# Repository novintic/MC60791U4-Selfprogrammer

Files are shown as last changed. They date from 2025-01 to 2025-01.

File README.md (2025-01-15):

This is a take at the MC68701/U4 self- programmer board published in application note AN906A/D by Motorola in 1987.

It allows the 'self-programming' of the MC68701(U4) microcontroller (basically an 6801 with built in Eprom).

Probably the only conceivable use for this thing nowadays is to program a 68701U4 to be used as a replacement for the custom 'PS4' chip on a Bubble Bobble arcade PCB. But if you read this you'll most likely already know that.

MC68701U4s are still more or less readily available on Ebay (either NOS or used).

Some additions and modifications to the original design have been made:
 - redesigned the power supply for the +21V programming voltage using an MC34063 based boost converter circuit
 - uses 27C512 ROMS as these are easily available and dirt cheap
 - Added a Vpp- Voltage LED: will light dim when 5V present and bright wenn 21V Vpp is switched on.

Usage: 
 - Eprom U3 must be programmed with the minprgu4.bin which contains the selfprogramming- code
 - Eprom U4 contains the image to be programmed to the MCU's Eprom (most likely 'a78-01.17' found in the 'bin'- folder).
 - Turn off Power (SW1), put SW2 in 'RESET' position
 - Insert the MC68701U4
 - Switch power on.'PWR' LED should light. 'Vpp' LED will be off (indicating /RST is low)
 - Switch SW2 to 'PRGRM'. 'Vpp' will light dim indicating 5V present at /RST which will take the MCU out of reset and rum minprgu4. At the same time LED 'BLANK' should light indicating blank check. If this check fails, both 'BLANK' and 'FAIL' LEDs will light.
 - If blank- check passes, minprgu4 will switch on Vpp. 'Vpp'- LED will light brightly. Programming of the MCU starts and will take approximately 4 minutes.
 - If programming was successful - which means that the data has been verified correctly - LED 'PASS' will light. If not, LED 'FAIL' will light.

-----------------------------------------------------------------------------------------------
IMPORTANT!

MINPRGU4 must be located from $1850-$1FFF on EPROM U3 (NOT starting from $1800 as the instructions in 'Self-Programming the MC68701/U4 document could be understood).

The Program on U4 must be at $1000-$1FFF on the EPROM U4 for MC68701U4 (for MC68701: $1800-$1FFF)

-----------------------------------------------------------------------------------------------

You can find more info here (also, most of the above changes are based on suggestions from this thread):
https://www.eevblog.com/forum/microcontrollers/self-programming-the-mc68701-and-the-mc68701u4-(motorola)/

This is another quick/messy release. the files have not really been cleaned up. You should be able to upload 'gerber.zip' to your favorite PCB manufacturer.

The board has been tested and works well for us, however, we'll not be able to offer any kind of support.  Please use at your own risk, thank you.

mirko(NOVINTIC) 01/2025

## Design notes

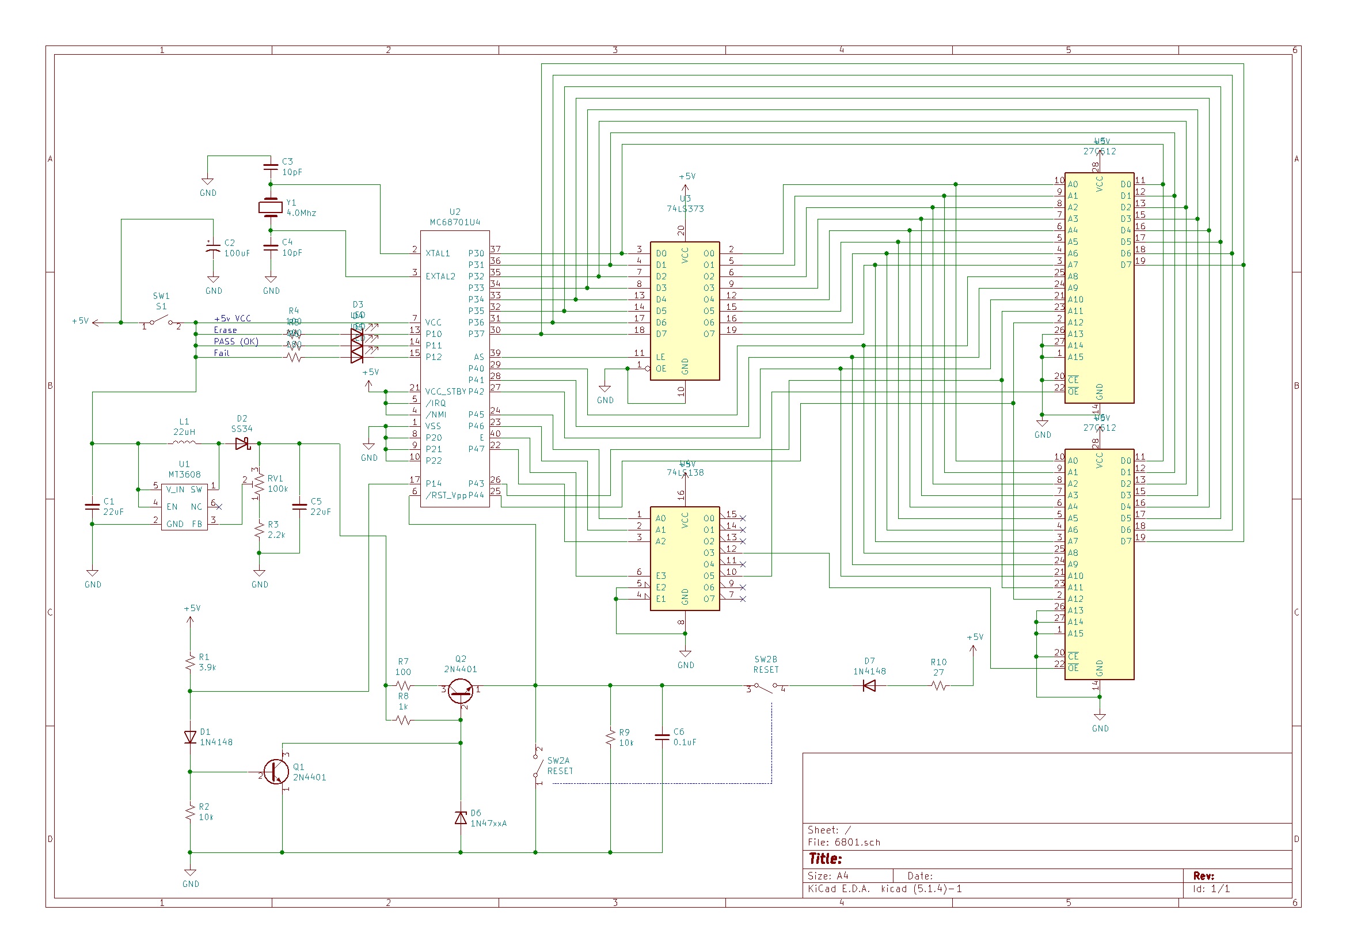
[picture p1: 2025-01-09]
Doc/68701u4.jpg

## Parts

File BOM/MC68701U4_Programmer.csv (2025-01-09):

Reference | Value | Footprint | Qty
C1 | 470uF(?) | Capacitor_THT:CP_Radial_D5.0mm_P2.50mm | 1
C2 | 1123pF | Capacitor_THT:C_Disc_D3.0mm_W2.0mm_P2.50mm | 1
C3 | 63uF | Capacitor_THT:CP_Radial_D5.0mm_P2.50mm | 1
C4,C5 | 10pF | Capacitor_THT:C_Disc_D3.0mm_W2.0mm_P2.50mm | 2
C6 | 100uF | Capacitor_THT:CP_Radial_D5.0mm_P2.50mm | 1
C7 | .1uF | Capacitor_THT:C_Disc_D3.0mm_W2.0mm_P2.50mm | 1
D1 | 1N5818/5819/5820 | Diode_THT:D_DO-34_SOD68_P7.62mm_Horizontal | 1
D2 | PWR | LED_THT:LED_D5.0mm_Clear | 1
D3 | Erase | LED_THT:LED_D5.0mm | 1
D4 | Pass (OK) | LED_THT:LED_D5.0mm | 1
D5 | Fail | LED_THT:LED_D5.0mm | 1
D6,D8 | D_Small | Diode_THT:D_DO-34_SOD68_P7.62mm_Horizontal | 2
D7 | 1N4748/1N5251 | Diode_THT:D_DO-34_SOD68_P7.62mm_Horizontal | 1
D9 | Vpp | LED_THT:LED_D5.0mm | 1
J1 | +5Vin | TerminalBlock:TerminalBlock_bornier-2_P5.08mm | 1
L1 | 88uH | footprints:IND_FIT68-1 | 1
Q1,Q2 | BC547 | Package_TO_SOT_THT:TO-92_HandSolder | 2
R1 | 1K | Resistor_THT:R_Axial_DIN0207_L6.3mm_D2.5mm_P10.16mm_Horizontal | 1
R2 | 20K | Resistor_THT:R_Axial_DIN0207_L6.3mm_D2.5mm_P10.16mm_Horizontal | 1
R3 | 0.23R | Resistor_THT:R_Axial_DIN0207_L6.3mm_D2.5mm_P10.16mm_Horizontal | 1
R4 | 180R | Resistor_THT:R_Axial_DIN0207_L6.3mm_D2.5mm_P10.16mm_Horizontal | 1
R5,R6,R7,R8 | 470R | Resistor_THT:R_Axial_DIN0207_L6.3mm_D2.5mm_P10.16mm_Horizontal | 4
R9 | 3.9K | Resistor_THT:R_Axial_DIN0207_L6.3mm_D2.5mm_P10.16mm_Horizontal | 1
R10,R12,R13 | 10K | Resistor_THT:R_Axial_DIN0207_L6.3mm_D2.5mm_P10.16mm_Horizontal | 3
R11 | 100R | Resistor_THT:R_Axial_DIN0207_L6.3mm_D2.5mm_P10.16mm_Horizontal | 1
R14 | 27R | Resistor_THT:R_Axial_DIN0207_L6.3mm_D2.5mm_P10.16mm_Horizontal | 1
R15 | 2K | Resistor_THT:R_Axial_DIN0207_L6.3mm_D2.5mm_P10.16mm_Horizontal | 1
SW1 | SW_DPDT_x2 | footprints:SW_GF-126-0159 | 1
SW2 | RST/PRG | footprints:SW_GF-126-0159 | 1
U1 | 74LS138 | Package_DIP:DIP-16_W7.62mm_Socket_LongPads | 1
U2 | 74LS373 | Package_DIP:DIP-20_W7.62mm_Socket_LongPads | 1
U3,U4 | 27C512 | Package_DIP:DIP-28_W15.24mm | 2
U5 | ~ | Package_DIP:DIP-40_W15.24mm_Socket_LongPads | 1
U6 | MC34063AD | Package_SO:SOIC-8_3.9x4.9mm_P1.27mm | 1
Y1 | 4Mhz | Crystal:Crystal_HC50_Vertical | 1

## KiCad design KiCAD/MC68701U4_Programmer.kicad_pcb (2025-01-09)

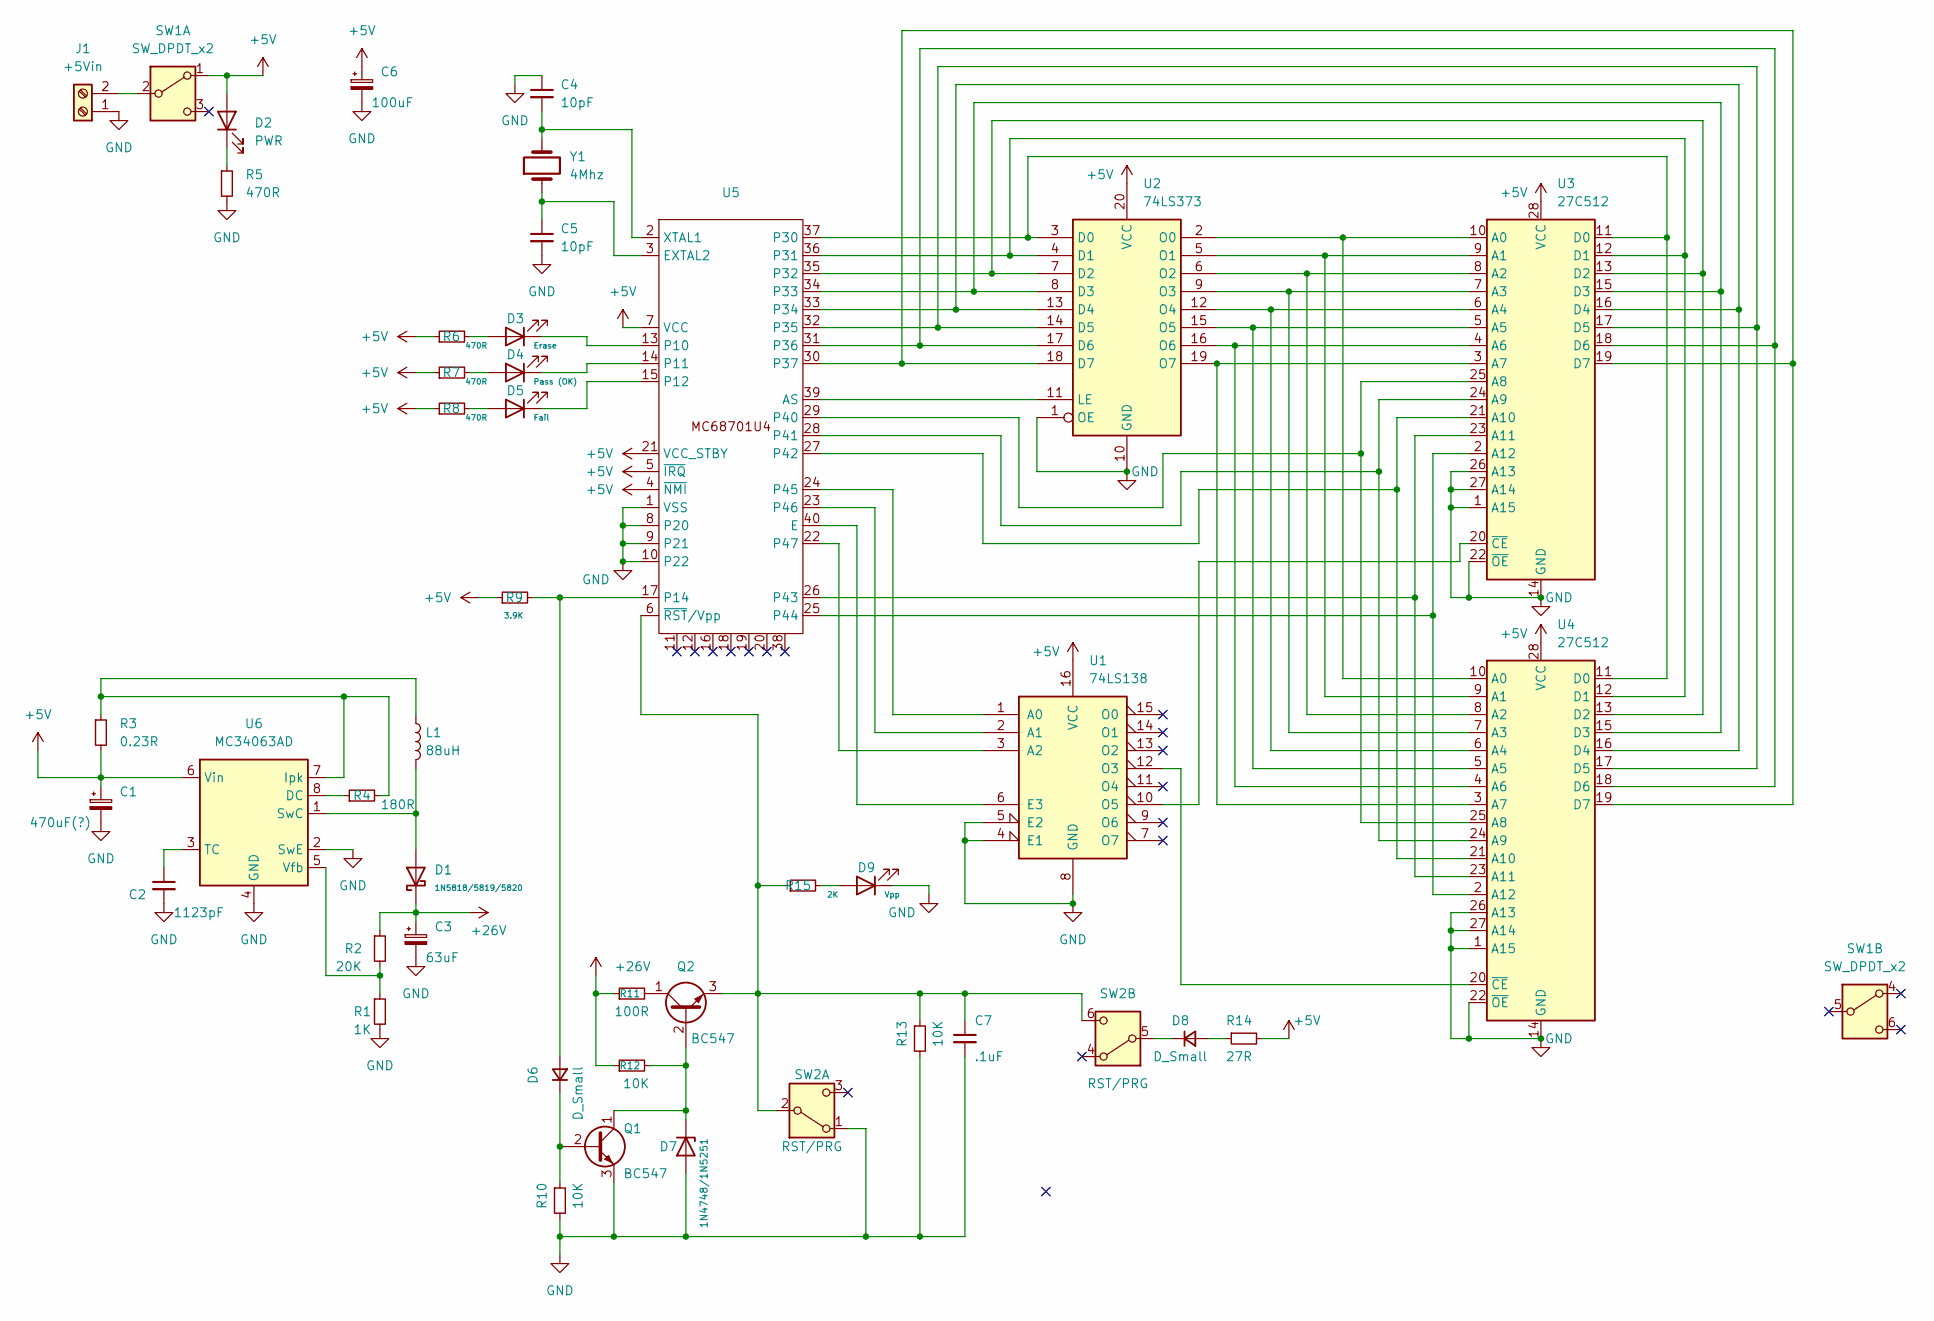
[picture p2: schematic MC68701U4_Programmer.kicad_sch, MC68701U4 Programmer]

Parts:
C1: 470uF(?); CP_Radial_D5.0mm_P2.50mm
C2: 1123pF; C_Disc_D3.0mm_W2.0mm_P2.50mm
C3: 63uF; CP_Radial_D5.0mm_P2.50mm
C4, C5: 10pF; C_Disc_D3.0mm_W2.0mm_P2.50mm
C6: 100uF; CP_Radial_D5.0mm_P2.50mm
C7: .1uF; C_Disc_D3.0mm_W2.0mm_P2.50mm
D1: 1N5818/5819/5820; D_DO-34_SOD68_P7.62mm_Horizontal
D2: PWR; LED_D5.0mm_Clear
D3: Erase; LED_D5.0mm
D4: Pass (OK); LED_D5.0mm
D5: Fail; LED_D5.0mm
D6, D8: D_Small; D_DO-34_SOD68_P7.62mm_Horizontal
D7: 1N4748/1N5251; D_DO-34_SOD68_P7.62mm_Horizontal
D9: Vpp; LED_D5.0mm
J1: +5Vin; TerminalBlock_bornier-2_P5.08mm
L1: 88uH; IND_FIT68-1
Q1, Q2: BC547; TO-92_HandSolder
R1: 1K; R_Axial_DIN0207_L6.3mm_D2.5mm_P10.16mm_Horizontal
R2: 20K; R_Axial_DIN0207_L6.3mm_D2.5mm_P10.16mm_Horizontal
R3: 0.23R; R_Axial_DIN0207_L6.3mm_D2.5mm_P10.16mm_Horizontal
R4: 180R; R_Axial_DIN0207_L6.3mm_D2.5mm_P10.16mm_Horizontal
R5, R6, R7, R8: 470R; R_Axial_DIN0207_L6.3mm_D2.5mm_P10.16mm_Horizontal
R9: 3.9K; R_Axial_DIN0207_L6.3mm_D2.5mm_P10.16mm_Horizontal
R10, R12, R13: 10K; R_Axial_DIN0207_L6.3mm_D2.5mm_P10.16mm_Horizontal
R11: 100R; R_Axial_DIN0207_L6.3mm_D2.5mm_P10.16mm_Horizontal
R14: 27R; R_Axial_DIN0207_L6.3mm_D2.5mm_P10.16mm_Horizontal
R15: 2K; R_Axial_DIN0207_L6.3mm_D2.5mm_P10.16mm_Horizontal
SW1: SW_DPDT_x2; SW_GF-126-0159
SW2: RST/PRG; SW_GF-126-0159
U1: 74LS138; DIP-16_W7.62mm_Socket_LongPads
U2: 74LS373; DIP-20_W7.62mm_Socket_LongPads
U3, U4: 27C512; DIP-28_W15.24mm
U5: DIP-40_W15.24mm_Socket_LongPads
U6: MC34063AD; SOIC-8_3.9x4.9mm_P1.27mm
Y1: 4Mhz; Crystal_HC50_Vertical

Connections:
+5V: C1.1, C6.1, D2.2 (A), R3.2, R6.1, R7.1, R8.1, R9.1, R14.2, SW1.1 (A), U1.16 (VCC), U2.20 (VCC), U3.28 (VCC), U4.28 (VCC), U5.4 (~NMI), U5.5 (~IRQ), U5.7 (VCC), U5.21 (VCC_STBY), U6.6 (Vin)
+26V: C3.1, D1.1 (K), R2.1, R11.1, R12.1
GND: C1.2, C2.2, C3.2, C4.1, C5.2, C6.2, C7.2, D7.2 (A), D9.1 (K), J1.1, Q1.3 (E), R1.2, R5.2, R10.2, R13.2, SW2.1 (A), U1.4 (E1), U1.5 (E2), U1.8 (GND), U2.1 (OE), U2.10 (GND), U3.1 (A15), U3.14 (GND), U3.22 (~OE), U3.26 (A13), U3.27 (A14), U4.1 (A15), U4.14 (GND), U4.22 (~OE), U4.26 (A13), U4.27 (A14), U5.1 (VSS), U5.8 (P20), U5.9 (P21), U5.10 (P22), U6.2 (SwE), U6.4 (GND)
unnamed: D1.2 (A), L1.2, U6.1 (SwC)
unnamed: D2.1 (K), R5.1
unnamed: D3.2 (A), R6.2
unnamed: D3.1 (K), U5.13 (P10)
unnamed: D4.2 (A), R7.2
unnamed: D4.1 (K), U5.14 (P11)
unnamed: D5.2 (A), R8.2
unnamed: D5.1 (K), U5.15 (P12)
unnamed: D6.2 (A), R9.2, U5.17 (P14)
unnamed: D6.1 (K), Q1.2 (B), R10.1
unnamed: D7.1 (K), Q1.1 (C), Q2.2 (B), R12.2
unnamed: D8.2 (A), R14.1
unnamed: D8.1 (K), SW2.5 (B)
unnamed: D9.2 (A), R15.2
unnamed: J1.2, SW1.2 (B)
unnamed: Q2.1 (C), R11.2
unnamed: C7.1, Q2.3 (E), R13.1, R15.1, SW2.2 (B), SW2.6 (C), U5.6 (~RST/Vpp)
unnamed: U1.1 (A0), U5.24 (P45)
unnamed: U1.2 (A1), U5.23 (P46)
unnamed: U1.3 (A2), U5.22 (P47)
unnamed: U1.6 (E3), U5.40 (E)
unnamed: U1.12 (O3), U4.20 (~CE)
unnamed: U1.10 (O5), U3.20 (~CE)
unnamed: U2.3 (D0), U3.11 (D0), U4.11 (D0), U5.37 (P30)
unnamed: U2.4 (D1), U3.12 (D1), U4.12 (D1), U5.36 (P31)
unnamed: U2.7 (D2), U3.13 (D2), U4.13 (D2), U5.35 (P32)
unnamed: U2.8 (D3), U3.15 (D3), U4.15 (D3), U5.34 (P33)
unnamed: U2.13 (D4), U3.16 (D4), U4.16 (D4), U5.33 (P34)
unnamed: U2.14 (D5), U3.17 (D5), U4.17 (D5), U5.32 (P35)
unnamed: U2.17 (D6), U3.18 (D6), U4.18 (D6), U5.31 (P36)
unnamed: U2.18 (D7), U3.19 (D7), U4.19 (D7), U5.30 (P37)
unnamed: U2.11 (LE), U5.39 (AS)
unnamed: U2.2 (O0), U3.10 (A0), U4.10 (A0)
unnamed: U2.5 (O1), U3.9 (A1), U4.9 (A1)
unnamed: U2.6 (O2), U3.8 (A2), U4.8 (A2)
unnamed: U2.9 (O3), U3.7 (A3), U4.7 (A3)
unnamed: U2.12 (O4), U3.6 (A4), U4.6 (A4)
unnamed: U2.15 (O5), U3.5 (A5), U4.5 (A5)
unnamed: U2.16 (O6), U3.4 (A6), U4.4 (A6)
unnamed: U2.19 (O7), U3.3 (A7), U4.3 (A7)
unnamed: U3.25 (A8), U4.25 (A8), U5.29 (P40)
unnamed: U3.24 (A9), U4.24 (A9), U5.28 (P41)
unnamed: U3.21 (A10), U4.21 (A10), U5.27 (P42)
unnamed: U3.23 (A11), U4.23 (A11), U5.26 (P43)
unnamed: U3.2 (A12), U4.2 (A12), U5.25 (P44)
unnamed: C5.1, U5.3 (EXTAL2), Y1.1
unnamed: C4.2, U5.2 (XTAL1), Y1.2
unnamed: R4.1, U6.8 (DC)
unnamed: L1.1, R3.1, R4.2, U6.7 (Ipk)
unnamed: C2.1, U6.3 (TC)
unnamed: R1.1, R2.2, U6.5 (Vfb)

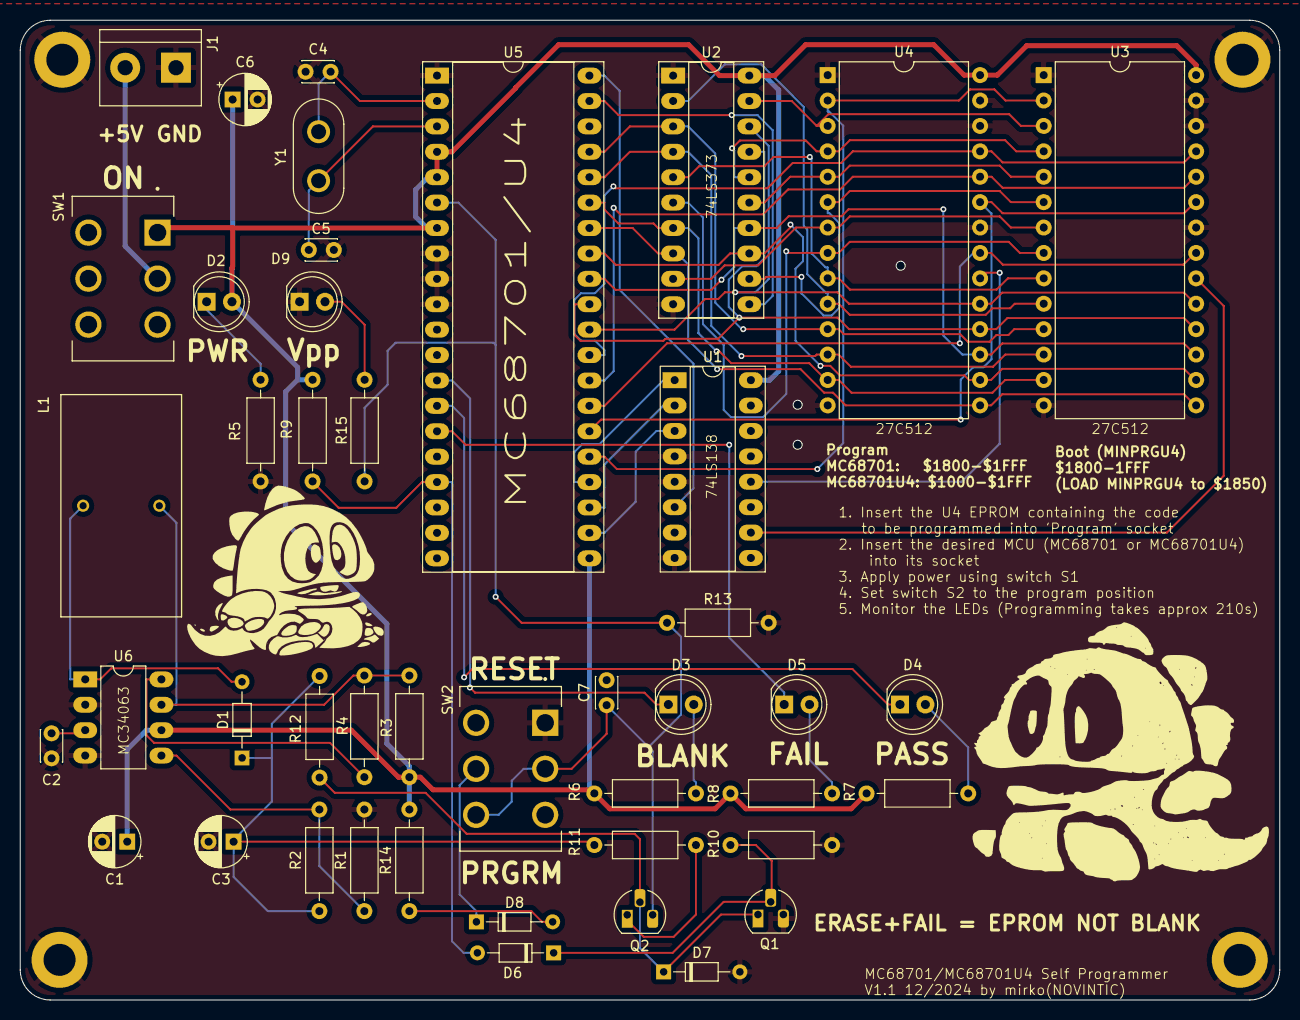
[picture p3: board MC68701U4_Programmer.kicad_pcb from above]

Board: 2 copper layers, 125.9 x 98.0 mm, 44 parts (0 on the bottom side), 54 nets.

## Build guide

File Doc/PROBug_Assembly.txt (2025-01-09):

I corrected the error, rechecked your work and changed the index back.   I reformatted things just so they line up to make it easier to read.    I ran it through if you want to check the listing file below.   I also included the S record.  Do you have a PROM programmer and part to load this code into?   If so, I think it's time to build up the circuit.   If you need help understanding how to build it, let me know.  You could do this on some white board for the small number of parts you want to program. 

S00A000042595445425547E3
S10B0080000000000000000074
S123B8508E00FF860797009702CEF800DF84C600A6001126298CFFFF27030820F3860697A3
S123B87002DF86CE004609CCC350D3097F0008DD0B8640950827FC8C000026EA20068683B5
S123B8909702205DCE7000DF80CE7FFFDF82CEC350DF86DE843CDE803C86FE9714A600DE03
S123B8B084A70008DF8486FC9714DC86D3097F0008DD0B8640950827FC38089C8223D9869E
S123B8D0FF971438DF84CE70003CA600DE84E60011261008DF8438088C800026EC868497F6
S10CB8F00220FE8682970220F872
S113BFF0B8F1B8F1B8F1B8F1B8F1B8F1B8F1B85096
S9030000FC

M6801 Portable Cross Assembler  0.05   MS-DOS/PC-DOS  Page 1
 Sat May 18 20:37:13 2019
Command line:
 C:\6801\PASM01.EXE -dxs -l BYTEBUG.lst BYTEBUG.asm
Options list:
ON  - b - Printing of macro definitions
ON  - c - Printing of macro calls
ON  - d - Placing of symbolic debugging information in COFF  (changed)
OFF - e - Printing of macro expansions
ON  - f - Printing of conditional directives
OFF - g - Printing of generated constants list
OFF - q - Expanding and printing of structured syntax
ON  - s - Printing of symbol table  (changed)
OFF - u - Printing of conditional unassembled source
ON  - x - Printing of cross reference table  (changed)
OFF - m - Suppress printing of error messages
ON  - w - Printing of warning messages
OFF - v - Suppress printing of updated status
OFF - y - Enabling of sgs extensions
ON  - o - Create object code
ON  -   - Formatting of source line listing
Create listing file - l - BYTEBUG.lst
 
Xdefs:
  NONE
 
Xrefs:
  NONE

Input file(s): BYTEBUG.asm (142 lines)
 
Output file: BYTEBUG.o 
Listing file: BYTEBUG.lst

M6801 Portable Cross Assembler  0.05  BYTEBUG.asm  Page 2
 Sat May 18 20:37:13 2019 
Options - MD,MC,NOG,NOU,W,NOMEX,CL,FMT,O
 
LINE   S PC   OPCO OPERANDS S LABEL    MNEMO OPERANDS COMMENT
00001                         *
00002                         *
00003                         * THIS PROGRAM WILL CHECK, PROGRAM AND VERIFY
00004                         * THE MC68701U4 ' S EPROM.
00005                         *
00006                         *
00007                         *         E Q U A T E S
00008  P 0000      0000     A P1DDR    EQU   $00      PORT 1 DATA DIR. REGISTER
00009  P 0000      0002     A P1DR     EQU   $02      PORT 1 DATA REGISTER
00010  P 0000      0008     A TCSR     EQU   $08      TIMER CONTROL/STAT REGISTER
00011  P 0000      0009     A TIMER    EQU   $09      COUNTER REGISTER
00012  P 0000      000b     A OUTCMP   EQU   $0B      OUTPUT COMPARE REGISTER
00013  P 0000      0014     A EPMCNT   EQU   $14      RAM/EROM CONTROL REGISTER
00014                         *
00015                         *         L O C A L       V A R I A B L E S
00016                         *
00017  A 0080                          ORG   $80     
00018  A 0080      02       A IMBEG    RMB   2        START OF MEMORY BLOCK
00019  A 0082      02       A IMEND    RMB   2        LAST BYTE OF MEMORY BLOCK
00020  A 0084      02       A PNTR     RMB   2        FIRST BYTE OF EPROM TO RE PGM'D
00021  A 0086      02       A WAIT     RMB   2        COUNTER VALUE
00022                         *
00023  A b850                          ORG   $B850   
00024  A b850 8e   00ff     A START    LDS   #$FF     INITIALIZE STACK
00025  A b853 86   07       A          LDAA  #$07     INIT. PORT 1
00026  A b855 97   00       A          STAA  P1DDR    DDR
00027  A b857 97   02       A          STAA  P1DR     DATA REGISTER (ALL LED'S OFF)
00028                         **
00029  A b859 ce   f800     A          LDX   #$F800   CHECK IF EPROM ERASED
00030  A b85c df   84       A          STX   PNTR     INIT. PNTR WHILE CONVENIENT
00031  A b85e c6   00       A          LDAB  #$00     GET READY FOR CMPR.
00032  A b860 a6   00       A ERASE    LDAA  0,X      LOAD EPROM CONTENTS
00033  A b862 11                       CBA            COMPARE TO ZERO
00034  A b863 26   29    b88e          BNE   ERROR1   BRANCH IF NOT ZERO
00035  A b865 8c   ffff     A          CPX   #$FFFF   
00036  A b868 27   03    b86d          BEQ   NEXT     IF SO BRANCH
00037  A b86a 08                       INX            GO AGAIN
00038  A b86b 20   f3    b860          BRA   ERASE   
00039                         **
00040  A b86d 86   06       A NEXT     LDAA  #$06     TURN ON ERASED LED
00041  A b86f 97   02       A          STAA  P1DR     
00042                         **
00043                         * WAIT FOR VPP TO REACH 21V (3.5 SEC.)
00044                         *
00045  A b871 df   86       A          STX   WAIT     
00046  A b873 ce   0046     A          LDX   #$0046   
00047  A b876 09              STALL1   DEX           
00048  A b877 cc   c350     A          LDD   #$C350   INIT. 50MS LOOP
00049  A b87a d3   09       A          ADDD  TIMER    BUMP CURRENT VALUE
00050  A b87c 7f   0008     A          CLR   TCSR     CLEAR OCF
00051  A b87f dd   0b       A          STD   OUTCMP   SET OUTPUT COMPARE
00052  A b881 86   40       A          LDAA  #$40     NOW WAIT FOR OFC

M6801 Portable Cross Assembler  0.05  BYTEBUG.asm  Page 3
 Sat May 18 20:37:13 2019 
Options - MD,MC,NOG,NOU,W,NOMEX,CL,FMT,O
 
LINE   S PC   OPCO OPERANDS S LABEL    MNEMO OPERANDS COMMENT
00053  A b883 95   08       A STALL2   BITA  TCSR     
00054  A b885 27   fc    b883          BEQ   STALL2   NOT YET
00055  A b887 8c   0000     A          CPX   #$0000   70 TIMES YET?
00056  A b88a 26   ea    b876          BNE   STALL1   NOPE
00057  A b88c 20   06    b894          BRA   PGINT   
00058                         **
00059  A b88e 86   83       A ERROR1   LDAA  #$83     LIGHT ERROR LED ONLY
00060  A b890 97   02       A          STAA  P1DR     
00061  A b892 20   5d    b8f1          BRA   SELF     
00062                         **
00063  A b894 ce   7000     A PGINT    LDX   #$7000   INIT. IMBEG
00064  A b897 df   80       A          STX   IMBEG   
00065  A b899 ce   7fff     A          LDX   #$7FFF   INIT. IMEND
00066  A b89c df   82       A          STX   IMEND   
00067  A b89e ce   c350     A          LDX   #$C350   INIT. WAIT (4.0 MHZ)
00068  A b8a1 df   86       A          STX   WAIT     
00069                         *
00070                         * THIS PART FROM 68701U4 DATA SHEET
00071                         *
00072  A b8a3 de   84       A EPROM    LDX   PNTR     SAVE CALLING ARGUMENT
00073  A b8a5 3c                       PSHX           RESTORE WHEN DONE
00074  A b8a6 de   80       A          LDX   IMBEG    USE STACK
00075                         *
00076  A b8a8 3c              EPRO02   PSHX           SAVE POINTER ON STACK
00077  A b8a9 86   fe       A          LDAA  #$FE     REMOVE VPP, SET LATCH
00078  A b8ab 97   14       A          STAA  EPMCNT   PPC=1,PLC=0
00079  A b8ad a6   00       A          LDAA  0,X      MOVE DATA MEMORY-TO-LATCH
00080  A b8af de   84       A          LDX   PNTR     GET WHERE TO PUT IT
00081  A b8b1 a7   00       A          STAA  0,X      STASH AND LATCH
00082  A b8b3 08                       INX            NEXT ADDR.
00083  A b8b4 df   84       A          STX   PNTR     ALL SET FOR NEXT
00084  A b8b6 86   fc       A          LDAA  #$FC     ENABLE EPROM POWER (VPP)
00085  A b8b8 97   14       A          STAA  EPMCNT   PPC=0,PLC=0
00086                         *
00087                         * NOW WAIT 50 MSEC TIMEOUT USING COMPARE
00088                         *
00089  A b8ba dc   86       A          LDD   WAIT     GET CYCLE COUNTER
00090  A b8bc d3   09       A          ADDD  TIMER    BUMP CURRENT VALUE
00091  A b8be 7f   0008     A          CLR   TCSR     CLEAR OCF
00092  A b8c1 dd   0b       A          STD   OUTCMP   SET OUTPUT COMPARE
00093  A b8c3 86   40       A          LDAA  #$40     NOW WAIT FOR OCF
00094  A b8c5 95   08       A EPRO04   BITA  TCSR     
00095  A b8c7 27   fc    b8c5          BEQ   EPRO04   NOT YET
00096                         *
00097  A b8c9 38                       PULX           SET UP FOR NEXT ONE
00098  A b8ca 08                       INX            NEXT
00099  A b8cb 9c   82       A          CPX   IMEND    MAYBE DONE
00100  A b8cd 23   d9    b8a8          BLS   EPRO02   NOT YET
00101  A b8cf 86   ff       A          LDAA  #$FF     REMOVE VPP, INHIBIT LATCH
00102  A b8d1 97   14       A          STAA  EPMCNT   EPROM CAN NOW RE READ
00103  A b8d3 38                       PULX           RESTORE PNTR
00104  A b8d4 df   84       A          STX   PNTR     

M6801 Portable Cross Assembler  0.05  BYTEBUG.asm  Page 4
 Sat May 18 20:37:13 2019 
Options - MD,MC,NOG,NOU,W,NOMEX,CL,FMT,O
 
LINE   S PC   OPCO OPERANDS S LABEL    MNEMO OPERANDS COMMENT
00105                         * *
00106                         * START NEW CODE
00107                         *
00108  A b8d6 ce   7000     A          LDX   #$7000   SET UP POINTER
00109  A b8d9 3c              VERF2    PSHX           SAVE POINTER ON STACK
00110  A b8da a6   00       A          LDAA  0,X      GET DESIRED DATA
00111  A b8dc de   84       A          LDX   PNTR     GET EPROM ADDR.
00112  A b8de e6   00       A          LDAB  0,X      GET DATA TO BE CHECKED
00113  A b8e0 11                       CBA            CHECK IF SAME
00114  A b8e1 26   10    b8f3          BNE   ERROR2   BRANCH IF ERROR(LIGHT LED)
00115  A b8e3 08                       INX            NEXT ADDR
00116  A b8e4 df   84       A          STX   PNTR     ALL SET FOR NEXT
00117  A b8e6 38                       PULX           SETUP FOR NEXT ONE
00118  A b8e7 08                       INX            NEXT
00119  A b8e8 8c   8000     A          CPX   #$8000   MAYBE DONE
00120  A b8eb 26   ec    b8d9          BNE   VERF2    NOT YET
00121                         **
00122  A b8ed 86   84       A          LDAA  #$84     
00123  A b8ef 97   02       A          STAA  P1DR     LIGHT VERIFY LED
00124                         **
00125  A b8f1 20   fe    b8f1 SELF     BRA   SELF     WAIT FOREVER
00126                         **
00127  A b8f3 86   82       A ERROR2   LDAA  #$82     LIGHT ERROR & ERASED LED'S
00128  A b8f5 97   02       A          STAA  P1DR     
00129  A b8f7 20   f8    b8f1          BRA   SELF     
00130                         **
00131                         * R E S T A R T   A N D   I N T R. V E C.
00132                         *
00133  A bff0                          ORG   $BFF0   
00134  A bff0      b8f1     A          FDB   SELF     
00135  A bff2      b8f1     A          FDB   SELF     
00136  A bff4      b8f1     A          FDB   SELF     
00137  A bff6      b8f1     A          FDB   SELF     
00138  A bff8      b8f1     A          FDB   SELF     
00139  A bffa      b8f1     A          FDB   SELF     
00140  A bffc      b8f1     A          FDB   SELF     
00141  A bffe      b850     A          FDB   START   
00142                                  END           

Total number of errors: 0
Total number of warnings: 0
Total number of lines: 142

Number of bytes in section ASCT: 193

Number of bytes in program: 193

M6801 Portable Cross Assembler  0.05     Page 5
 Sat May 18 20:37:13 2019 
 
           CROSS REFERENCE TABLE
NAME    ATTRB S VALUE P:LINE LINE1....N
 
EPMCNT   EQU  A 0014  2:13          78   85  102
EPRO02        A b8a8  3:76         100
EPRO04        A b8c5  3:94          95
EPROM         A b8a3  3:72       
ERASE         A b860  2:32          38
ERROR1        A b88e  3:59          34
ERROR2        A b8f3  4:127        114
IMBEG         A 0080  2:18          64   74
IMEND         A 0082  2:19          66   99
NEXT          A b86d  2:40          36
OUTCMP   EQU  A 000b  2:12          51   92
P1DDR    EQU  A 0000  2:8           26
P1DR     EQU  A 0002  2:9           27   41   60  123  128
PGINT         A b894  3:63          57
PNTR          A 0084  2:20          30   72   80   83  104  111  116
SELF          A b8f1  4:125         61  125  129  134  135  136  137  138  139  140
STALL1        A b876  2:47          56
STALL2        A b883  3:53          54
START         A b850  2:24         141
TCSR     EQU  A 0008  2:10          50   53   91   94
TIMER    EQU  A 0009  2:11          49   90
VERF2         A b8d9  4:109        120
WAIT          A 0086  2:21          45   68   89
« Last Edit: May 19, 2019, 12:52:05 am by joeqsmith »
